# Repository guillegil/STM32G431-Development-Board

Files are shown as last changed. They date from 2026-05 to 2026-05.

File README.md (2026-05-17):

# STM32G431 Development Board

KiCad 10 design files for a small development board based on the STMicroelectronics
STM32G431CBT6 microcontroller (Cortex-M4F, 170 MHz, 128 KB flash, USB).

This is a personal learning project — my first custom-designed PCB, built as
preparation for a more complex nRF5340-based wireless keyboard development board.

## Features

- STM32G431CBT6 in LQFP-48 package (hand-solderable)
- USB-C connector for power and native USB device communication
- 3.3 V LDO regulator
- SWD programming header
- UART debug header
- User LED + user button
- Reset button + boot-mode jumper
- GPIO breakout headers for experimentation

## Project goals

- Learn KiCad 10 schematic and PCB design workflow
- Learn home reflow soldering (hot plate + hot air)
- Build a base for future Zephyr RTOS experimentation
- Prepare skills for a larger custom-keyboard project

## Status

🟡 In design — schematic in progress

## Tools used

- KiCad 10.x
- Zephyr RTOS / nRF Connect SDK (firmware, future)
- JLCPCB (PCB fabrication, planned)

## License

See [LICENSE](LICENSE). This project is open source under the MIT License.

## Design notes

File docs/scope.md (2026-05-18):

# STM32G431 Dev Board — Project Scope

**Project:** `stm32g431-devboard`
**Goal:** A learning-focused STM32 development board for KiCad practice and future firmware experimentation.
**Out of:** Commercial product, certification target, or anything that needs to "just work" without iteration.

---

## Goals (what success looks like)

1. Functional STM32G431 dev board that boots, runs firmware, and is debuggable
2. Hand-soldered by user (no PCBA service for v1)
3. Manufactured at JLCPCB, assembled in user's workshop
4. Used as both a learning artifact AND a "brain module" for future projects
5. Documents the user's KiCad and STM32 skills development

---

## In scope (locked feature list)

### Power
- USB-C input (GCT USB4085) with 5.1kΩ CC pull-downs
- Diode-OR power input: USB + external (JST-PH 2-pin) both Schottky-protected
- Dual LDO selector (AP2112K-3.3 + MCP1700-3302E/TT) via 3-pin jumper
- Power LEDs with disable jumpers (red on VBUS, green on +3V3_RAW)
- Current measurement jumper between +3V3_RAW and +3V3

### MCU support
- STM32G431CBT6 (LQFP-48)
- VDD decoupling: 3× 100nF + 1× 4.7µF
- VDDA filter: ferrite bead + 1µF + 10nF
- VREF+ selector jumper (internal +3V3A vs external via 1kΩ)
- VBAT tied to +3V3 (no battery backup)

### Programming & debug
- SWD 5-pin header
- Reset button + 100nF noise cap
- BOOT0 button (PB8) + 10kΩ pull-down
- USB-C handles DFU flashing + USB CDC virtual UART (firmware-level)
- Physical UART header (USART2 on PA2/PA3) as backup debug

### User I/O
- User LED on PA5 (1kΩ current limit)
- User button on PB1 with 10kΩ pull-up
- **3× WS2812B addressable RGB LEDs** on PA0 (TIM2_CH1)
- **74AHCT125 level shifter** (3.3V → 5V) for RGB data line

### Protection
- **USBLC6-2SC6 ESD protection** on USB D+/D− lines

### Connectivity
- **GPIO breakout: Black Pill style** (2× single-row 2.54mm headers, ~40-pin DIP form factor)
- Breadboard-friendly board width

### Documentation on PCB
- Pin labels / silkscreen legends
- Test points on key signals (VDD, GND, +3V3A, key debug points)
- Board name + version on silk
- Polarity markings on diodes, LEDs, electrolytic caps

---

## Explicitly OUT of scope (for v1)

These were considered and **deliberately deferred**:

- ❌ Battery management (TP4056 + DW01A + power path) — separate "Battery Management Board" project
- ❌ Buck/boost converter — LDO is sufficient for USB power; buck-boost adds complexity not needed here
- ❌ External crystal — STM32G4 has internal HSI48 + USB clock recovery, no crystal needed
- ❌ Wireless (BLE/WiFi) — separate nRF5340 project
- ❌ Mounting holes — not selected by user (can add to v2 if needed)
- ❌ Sensors (BME280, IMU, etc.) — out of scope
- ❌ Displays (OLED, LCD) — out of scope
- ❌ Audio codec — out of scope
- ❌ More than 3 RGB LEDs — sufficient for "addressable demo"
- ❌ APA102 (SPI-based RGB) — chose WS2812B for the DMA learning value

---

## v2 candidates (good ideas saved for later)

Captured here so we don't lose them, NOT committed to v1:

- Mounting holes (3.2mm clearance for M3 standoffs)
- USB-PD capable connector + IC (negotiate higher voltage from PD chargers)
- I²C-style "QWIIC" connector for sensor expansion
- Tag-Connect SWD pads (smaller footprint than 5-pin header)
- Battery charging via TP4056 + protection IC
- Crystal footprint (DNP by default) for future precise timing experiments
- 4-layer PCB upgrade for better RF/EMI
- Pin labels on bottom silk too (for when board is flipped)

---

## Status snapshot (update as we progress)

### ✅ Done in schematic
- USB-C power input + diode-OR
- Dual LDO selector + LEDs + jumpers
- Current measurement jumper
- MCU VDD/VSS/VBAT/VDDA decoupling
- VREF+ selector
- USB_DP/USB_DM correctly wired (PA12/PA11)
- SWD header
- Reset button + noise cap
- BOOT0 button + pull-down

### 🔜 Pending schematic (in priority order)
1. User LED (PA5) + 1kΩ resistor
2. User button (PB1) + 10kΩ pull-up
3. USBLC6-2SC6 ESD protection on USB data lines
4. Physical UART header (USART2 / PA2,PA3)
5. RGB LED block: 3× WS2812B + 74AHCT125 + decoupling
6. GPIO breakout headers (Black Pill style, both sides)

### ⏳ PCB layout phase (not started)
- Component placement
- Routing
- Ground pour
- Silkscreen labels & test points
- DRC + 3D check

### ⏳ Fabrication phase (not started)
- Gerbers
- BOM
- JLCPCB order

---

## When new feature ideas arise

**Rule:** if it's not in "In scope" above, default answer is **v2**.

The only exception: a genuine v1 requirement we missed. In that case, the trade-off should be:
- Add the new feature **and** remove something from v1, OR
- Add to v1 only if it's <30 min of work and doesn't change architecture

If the answer is "but it would be cool" → v2.

---

*Last updated: Session creating addressable RGB LED + GPIO breakout decisions*

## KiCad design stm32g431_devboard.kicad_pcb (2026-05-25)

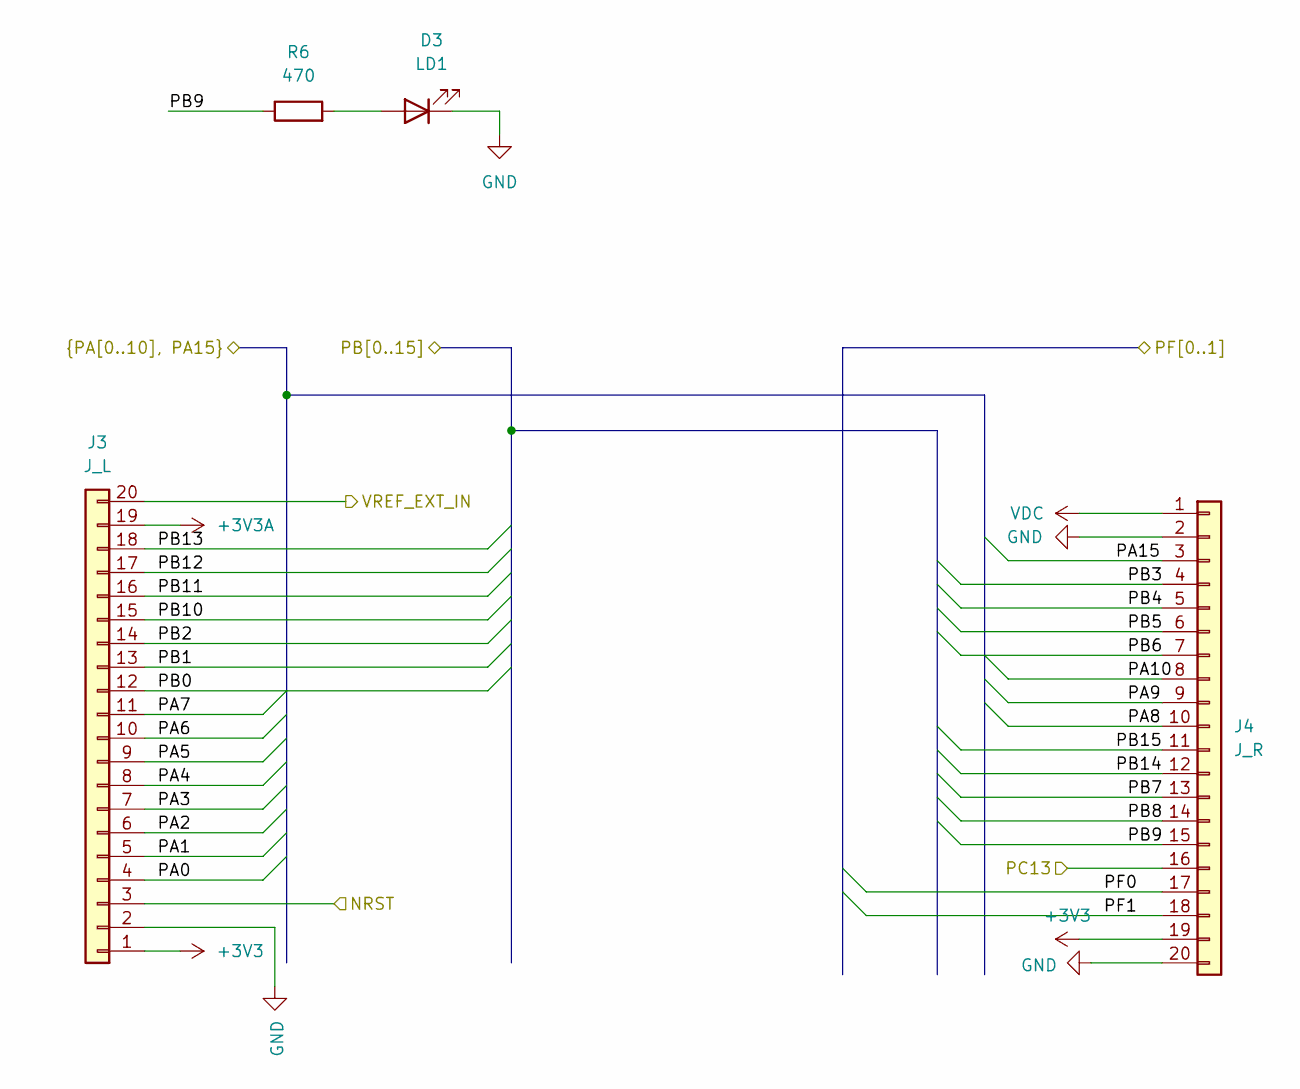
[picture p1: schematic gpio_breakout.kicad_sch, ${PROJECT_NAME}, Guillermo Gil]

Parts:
D3: LD1; LED_0603_1608Metric_Pad1.05x0.95mm_HandSolder
J3: J_L; PinHeader_1x20_P2.54mm_Vertical
J4: J_R; PinHeader_1x20_P2.54mm_Vertical
R6: 470; R_0603_1608Metric_Pad0.98x0.95mm_HandSolder

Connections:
+3V3: J3.1, J4.19; also elsewhere on the board
+3V3A: J3.19; also elsewhere on the board
/GPIO Breakout/PA0: J3.4; also elsewhere on the board
/GPIO Breakout/PA1: J3.5; also elsewhere on the board
/GPIO Breakout/PA2: J3.6; also elsewhere on the board
/GPIO Breakout/PA3: J3.7; also elsewhere on the board
/GPIO Breakout/PA4: J3.8; also elsewhere on the board
/GPIO Breakout/PA5: J3.9; also elsewhere on the board
/GPIO Breakout/PA6: J3.10; also elsewhere on the board
/GPIO Breakout/PA7: J3.11; also elsewhere on the board
/GPIO Breakout/PA8: J4.10; also elsewhere on the board
/GPIO Breakout/PA9: J4.9; also elsewhere on the board
/GPIO Breakout/PA10: J4.8; also elsewhere on the board
/GPIO Breakout/PA15: J4.3; also elsewhere on the board
/GPIO Breakout/PB0: J3.12; also elsewhere on the board
/GPIO Breakout/PB1: J3.13; also elsewhere on the board
/GPIO Breakout/PB2: J3.14; also elsewhere on the board
/GPIO Breakout/PB3: J4.4; also elsewhere on the board
/GPIO Breakout/PB4: J4.5; also elsewhere on the board
/GPIO Breakout/PB5: J4.6; also elsewhere on the board
/GPIO Breakout/PB6: J4.7; also elsewhere on the board
/GPIO Breakout/PB7: J4.13; also elsewhere on the board
/GPIO Breakout/PB8: J4.14; also elsewhere on the board
/GPIO Breakout/PB9: J4.15, R6.1; also elsewhere on the board
/GPIO Breakout/PB10: J3.15; also elsewhere on the board
/GPIO Breakout/PB11: J3.16; also elsewhere on the board
/GPIO Breakout/PB12: J3.17; also elsewhere on the board
/GPIO Breakout/PB13: J3.18; also elsewhere on the board
/GPIO Breakout/PB14: J4.12; also elsewhere on the board
/GPIO Breakout/PB15: J4.11; also elsewhere on the board
/GPIO Breakout/PF0: J4.17; also elsewhere on the board
/GPIO Breakout/PF1: J4.18; also elsewhere on the board
/GPIO Breakout/VREF_EXT_IN: J3.20; also elsewhere on the board
/MCU/NRST: J3.3; also elsewhere on the board
/MCU/PC13: J4.16; also elsewhere on the board
GND: D3.1 (K), J3.2, J4.2, J4.20; also elsewhere on the board
unnamed: D3.2 (A), R6.2
VDC: J4.1; also elsewhere on the board

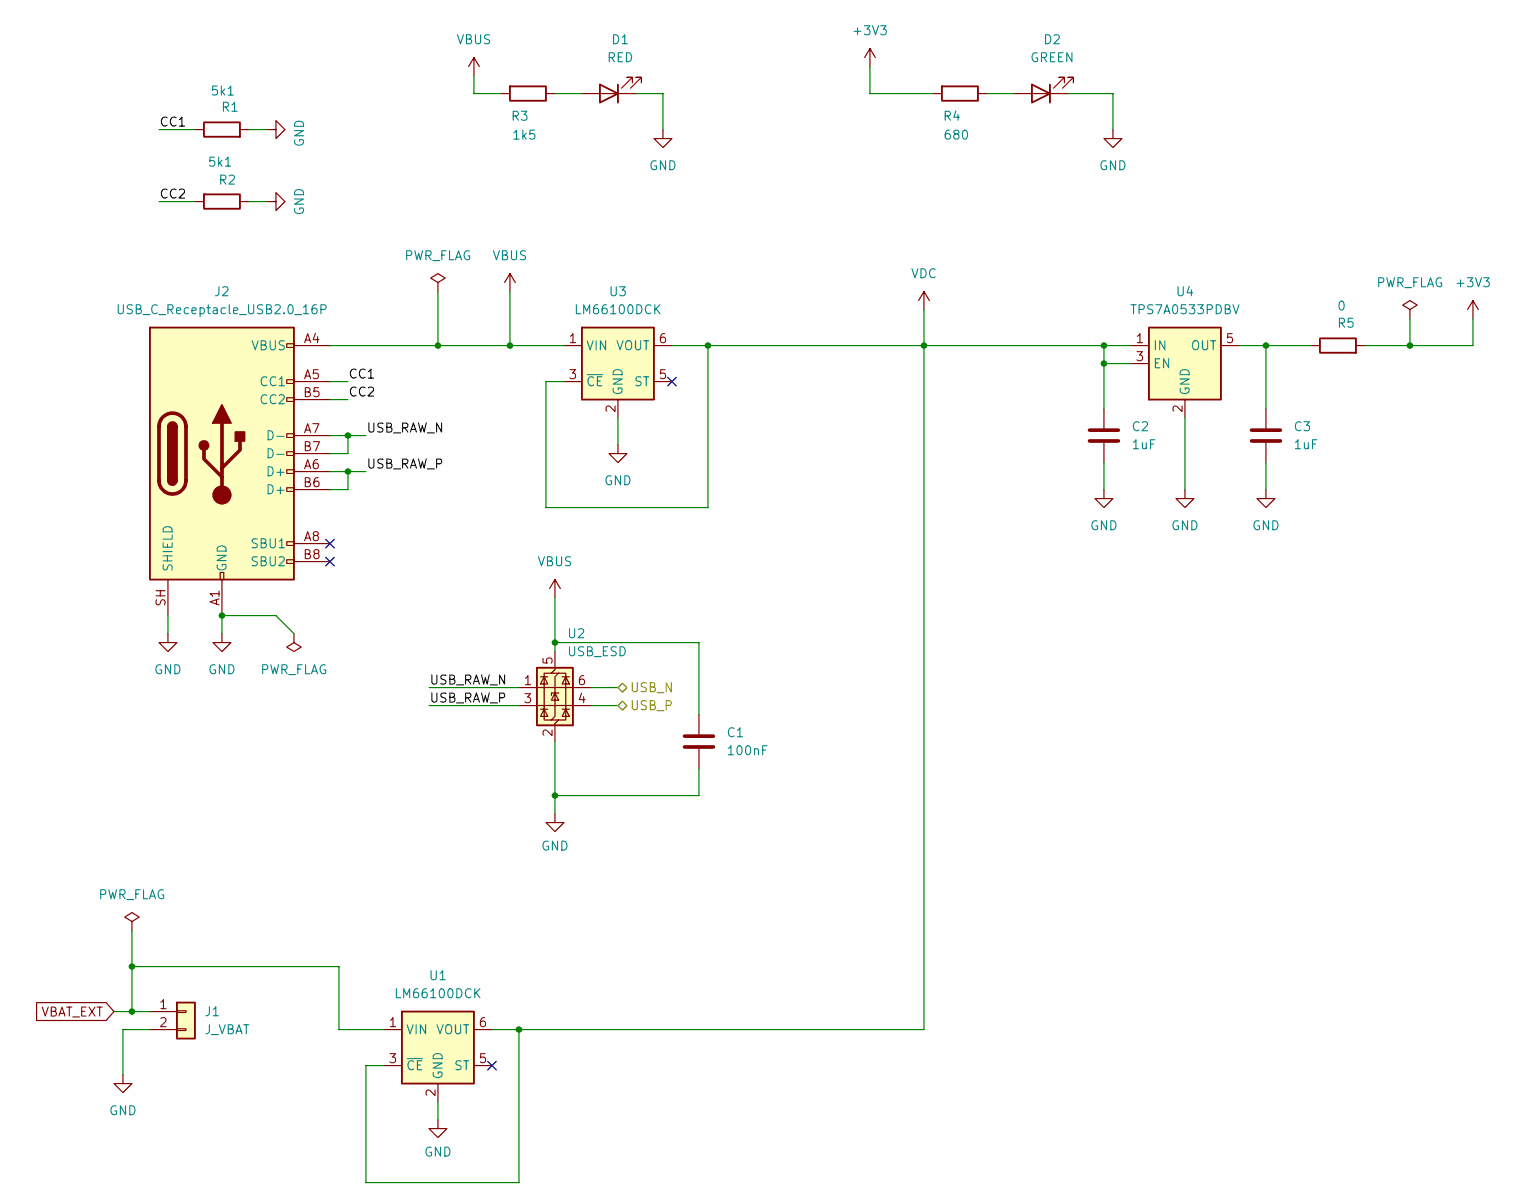
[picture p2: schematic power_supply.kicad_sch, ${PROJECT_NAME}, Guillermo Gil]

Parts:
C1: 100nF; C_0603_1608Metric_Pad1.08x0.95mm_HandSolder
C2, C3: 1uF; C_0603_1608Metric_Pad1.08x0.95mm_HandSolder
D1: RED; LED_0603_1608Metric_Pad1.05x0.95mm_HandSolder
D2: GREEN; LED_0603_1608Metric_Pad1.05x0.95mm_HandSolder
J1: J_VBAT; PinHeader_1x02_P2.54mm_Vertical
J2: USB_C_Receptacle_USB2.0_16P; USB_C_Receptacle_GCT_USB4085
R1, R2: 5k1; R_0603_1608Metric_Pad0.98x0.95mm_HandSolder
R3: 1k5; R_0603_1608Metric_Pad0.98x0.95mm_HandSolder
R4: 680; R_0603_1608Metric_Pad0.98x0.95mm_HandSolder
R5: 0; R_0603_1608Metric_Pad0.98x0.95mm_HandSolder
U1, U3: LM66100DCK; SOT-363_SC-70-6
U2: USB_ESD; SOT-23-6
U4: TPS7A0533PDBV; SOT-23-5_HandSoldering

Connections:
+3V3: R4.2, R5.2; also elsewhere on the board
/MCU/USB_N: U2.6 (I/O1); also elsewhere on the board
/MCU/USB_P: U2.4 (I/O2); also elsewhere on the board
/Power Supply/CC1: J2.A5 (CC1), R1.1
/Power Supply/CC2: J2.B5 (CC2), R2.2
/Power Supply/USB_RAW_N: J2.A7 (D-), J2.B7 (D-), U2.1 (I/O1)
/Power Supply/USB_RAW_P: J2.A6 (D+), J2.B6 (D+), U2.3 (I/O2)
GND: C1.2, C2.2, C3.2, D1.1 (K), D2.1 (K), J1.2, J2.A1 (GND), J2.A12 (GND), J2.B1 (GND), J2.B12 (GND), J2.SH (SHIELD), R1.2, R2.1, U1.2 (GND), U2.2 (GND), U3.2 (GND), U4.2 (GND); also elsewhere on the board
unnamed: D1.2 (A), R3.1
unnamed: D2.2 (A), R4.1
unnamed: C3.1, R5.1, U4.5 (OUT)
VBAT_EXT: J1.1, U1.1 (VIN)
VBUS: C1.1, J2.A4 (VBUS), J2.A9 (VBUS), J2.B4 (VBUS), J2.B9 (VBUS), R3.2, U2.5 (VBUS), U3.1 (VIN)
VDC: C2.1, U1.3 (~CE), U1.6 (VOUT), U3.3 (~CE), U3.6 (VOUT), U4.1 (IN), U4.3 (EN); also elsewhere on the board

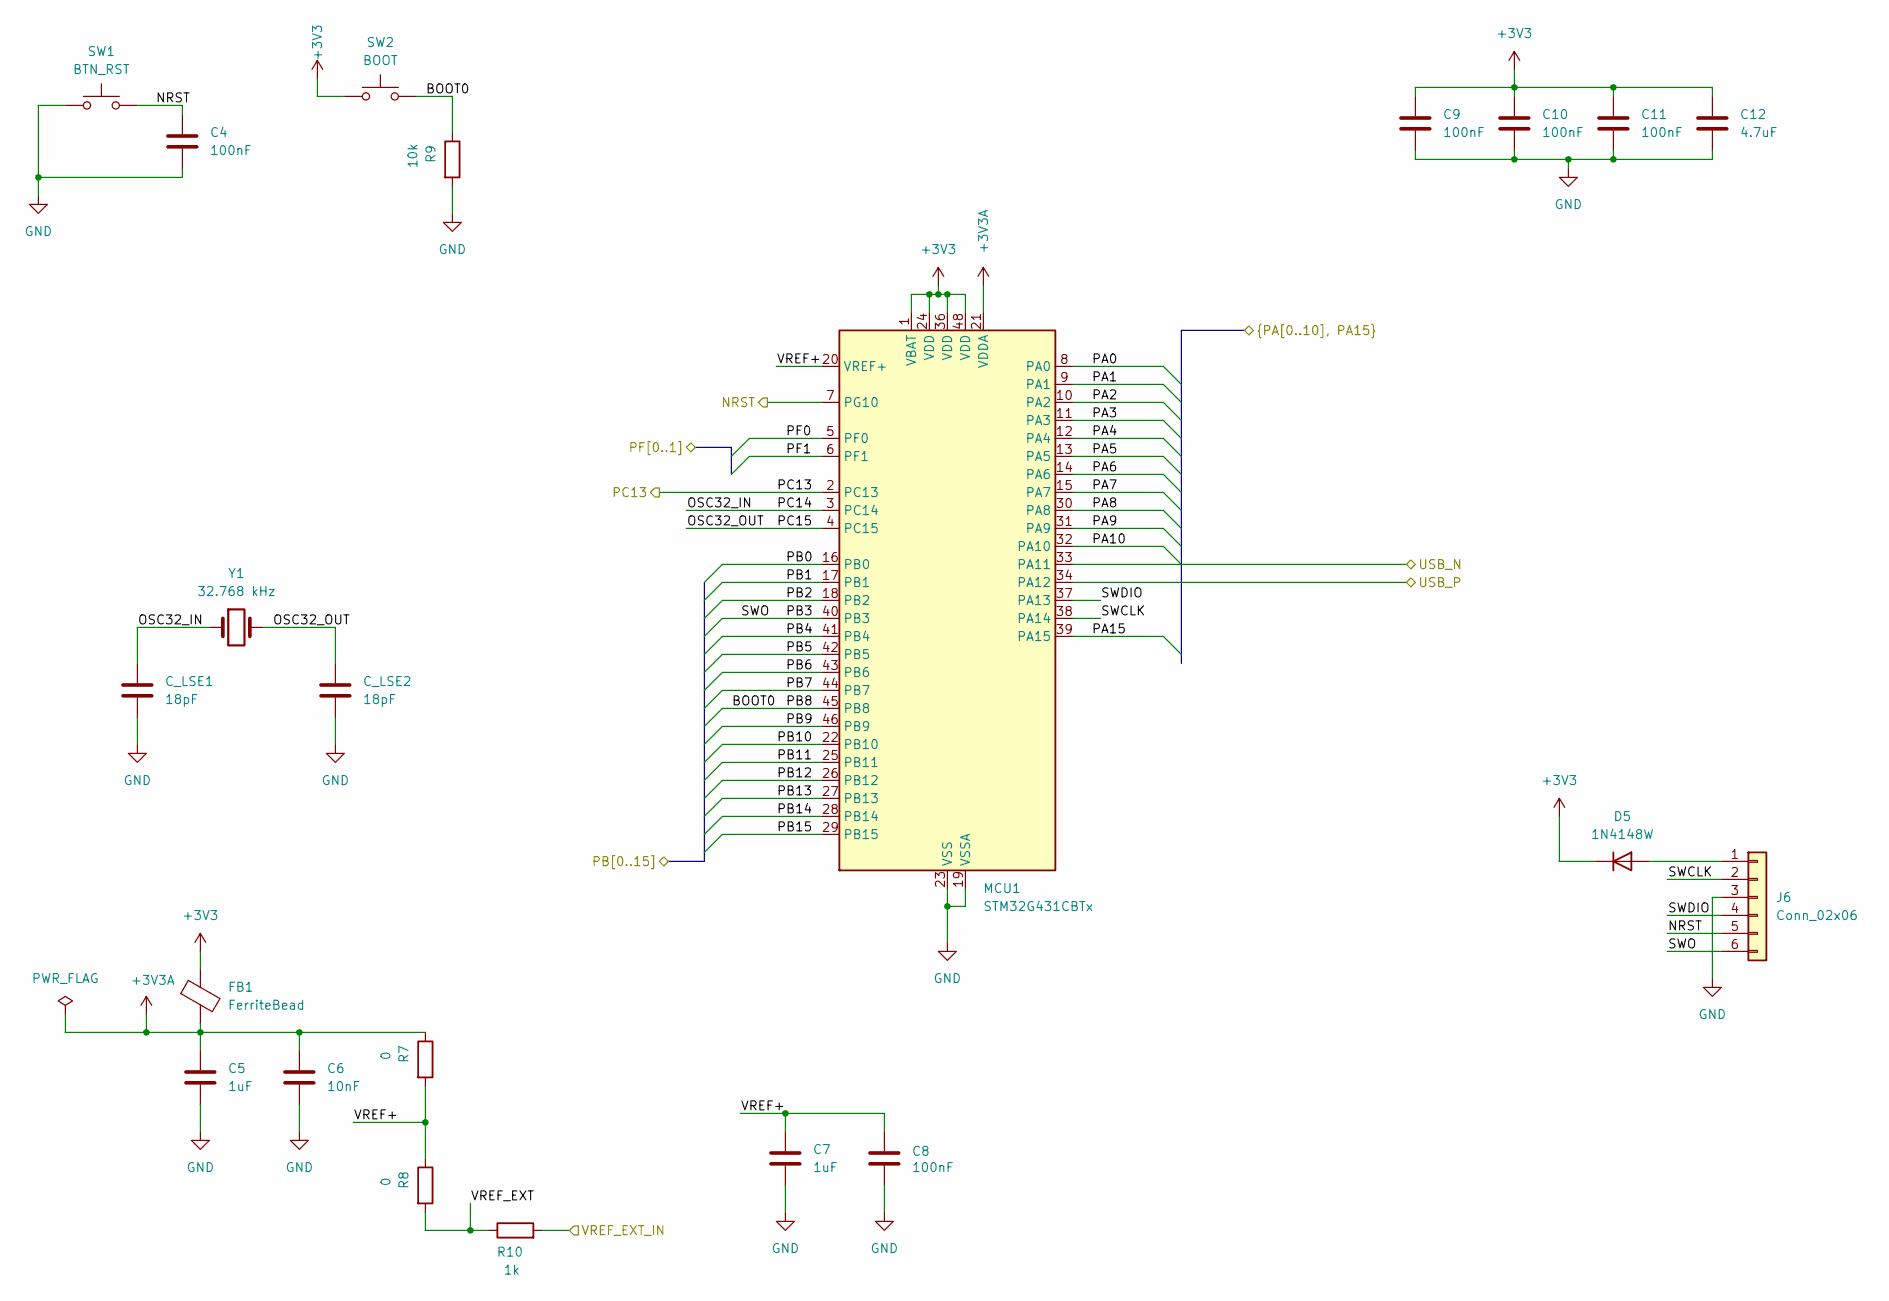
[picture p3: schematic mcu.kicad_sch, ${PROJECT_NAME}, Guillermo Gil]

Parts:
C4, C8, C9, C10, C11: 100nF; C_0603_1608Metric_Pad1.08x0.95mm_HandSolder
C5, C7: 1uF; C_0603_1608Metric_Pad1.08x0.95mm_HandSolder
C6: 10nF; C_0603_1608Metric_Pad1.08x0.95mm_HandSolder
C12: 4.7uF; C_0603_1608Metric_Pad1.08x0.95mm_HandSolder
C_LSE1, C_LSE2: 18pF; C_0603_1608Metric_Pad1.08x0.95mm_HandSolder
D5: 1N4148W; D_SOD-323
FB1: FerriteBead; L_0603_1608Metric_Pad1.05x0.95mm_HandSolder
J6: Conn_02x06; PinHeader_2x03_P2.54mm_Vertical_SMD
MCU1: STM32G431CBTx; LQFP-48_7x7mm_P0.5mm
R7, R8: 0; R_0603_1608Metric_Pad0.98x0.95mm_HandSolder
R9: 10k; R_0603_1608Metric_Pad0.98x0.95mm_HandSolder
R10: 1k; R_0603_1608Metric_Pad0.98x0.95mm_HandSolder
SW1: BTN_RST; SW_SPST_PTS810
SW2: BOOT; SW_SPST_PTS810
Y1: 32.768 kHz; Crystal_SMD_3215-2Pin_3.2x1.5mm

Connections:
+3V3: C9.1, C10.1, C11.1, C12.1, D5.1 (K), FB1.1, MCU1.1 (VBAT), MCU1.24 (VDD), MCU1.36 (VDD), MCU1.48 (VDD), SW2.1; also elsewhere on the board
+3V3A: C5.1, C6.1, FB1.2, MCU1.21 (VDDA), R7.1; also elsewhere on the board
/GPIO Breakout/PA0: MCU1.8 (PA0); also elsewhere on the board
/GPIO Breakout/PA1: MCU1.9 (PA1); also elsewhere on the board
/GPIO Breakout/PA2: MCU1.10 (PA2); also elsewhere on the board
/GPIO Breakout/PA3: MCU1.11 (PA3); also elsewhere on the board
/GPIO Breakout/PA4: MCU1.12 (PA4); also elsewhere on the board
/GPIO Breakout/PA5: MCU1.13 (PA5); also elsewhere on the board
/GPIO Breakout/PA6: MCU1.14 (PA6); also elsewhere on the board
/GPIO Breakout/PA7: MCU1.15 (PA7); also elsewhere on the board
/GPIO Breakout/PA8: MCU1.30 (PA8); also elsewhere on the board
/GPIO Breakout/PA9: MCU1.31 (PA9); also elsewhere on the board
/GPIO Breakout/PA10: MCU1.32 (PA10); also elsewhere on the board
/GPIO Breakout/PA15: MCU1.39 (PA15); also elsewhere on the board
/GPIO Breakout/PB0: MCU1.16 (PB0); also elsewhere on the board
/GPIO Breakout/PB1: MCU1.17 (PB1); also elsewhere on the board
/GPIO Breakout/PB2: MCU1.18 (PB2); also elsewhere on the board
/GPIO Breakout/PB3: J6.6, MCU1.40 (PB3); also elsewhere on the board
/GPIO Breakout/PB4: MCU1.41 (PB4); also elsewhere on the board
/GPIO Breakout/PB5: MCU1.42 (PB5); also elsewhere on the board
/GPIO Breakout/PB6: MCU1.43 (PB6); also elsewhere on the board
/GPIO Breakout/PB7: MCU1.44 (PB7); also elsewhere on the board
/GPIO Breakout/PB8: MCU1.45 (PB8), R9.1, SW2.2; also elsewhere on the board
/GPIO Breakout/PB9: MCU1.46 (PB9); also elsewhere on the board
/GPIO Breakout/PB10: MCU1.22 (PB10); also elsewhere on the board
/GPIO Breakout/PB11: MCU1.25 (PB11); also elsewhere on the board
/GPIO Breakout/PB12: MCU1.26 (PB12); also elsewhere on the board
/GPIO Breakout/PB13: MCU1.27 (PB13); also elsewhere on the board
/GPIO Breakout/PB14: MCU1.28 (PB14); also elsewhere on the board
/GPIO Breakout/PB15: MCU1.29 (PB15); also elsewhere on the board
/GPIO Breakout/PF0: MCU1.5 (PF0); also elsewhere on the board
/GPIO Breakout/PF1: MCU1.6 (PF1); also elsewhere on the board
/GPIO Breakout/VREF_EXT_IN: R10.2; also elsewhere on the board
/MCU/NRST: C4.1, J6.5, MCU1.7 (PG10), SW1.2; also elsewhere on the board
/MCU/OSC32_IN: C_LSE1.1, MCU1.3 (PC14), Y1.1
/MCU/OSC32_OUT: C_LSE2.1, MCU1.4 (PC15), Y1.2
/MCU/PC13: MCU1.2 (PC13); also elsewhere on the board
/MCU/SWCLK: J6.2, MCU1.38 (PA14)
/MCU/SWDIO: J6.4, MCU1.37 (PA13)
/MCU/USB_N: MCU1.33 (PA11); also elsewhere on the board
/MCU/USB_P: MCU1.34 (PA12); also elsewhere on the board
/MCU/VREF+: C7.1, C8.1, MCU1.20 (VREF+), R7.2, R8.1
/MCU/VREF_EXT: R8.2, R10.1
GND: C4.2, C5.2, C6.2, C7.2, C8.2, C9.2, C10.2, C11.2, C12.2, C_LSE1.2, C_LSE2.2, J6.3, MCU1.19 (VSSA), MCU1.23 (VSS), MCU1.35 (VSS), MCU1.47 (VSS), R9.2, SW1.1; also elsewhere on the board
unnamed: D5.2 (A), J6.1

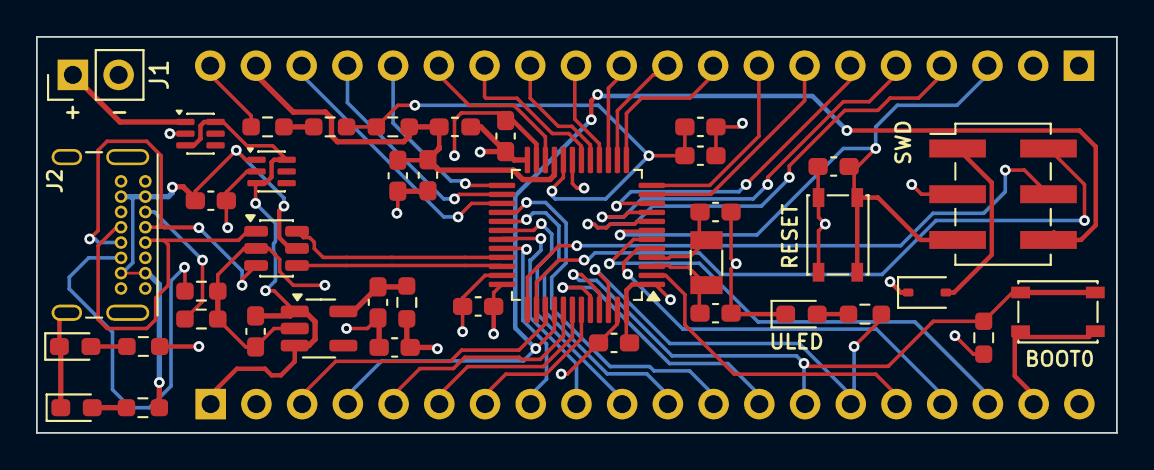
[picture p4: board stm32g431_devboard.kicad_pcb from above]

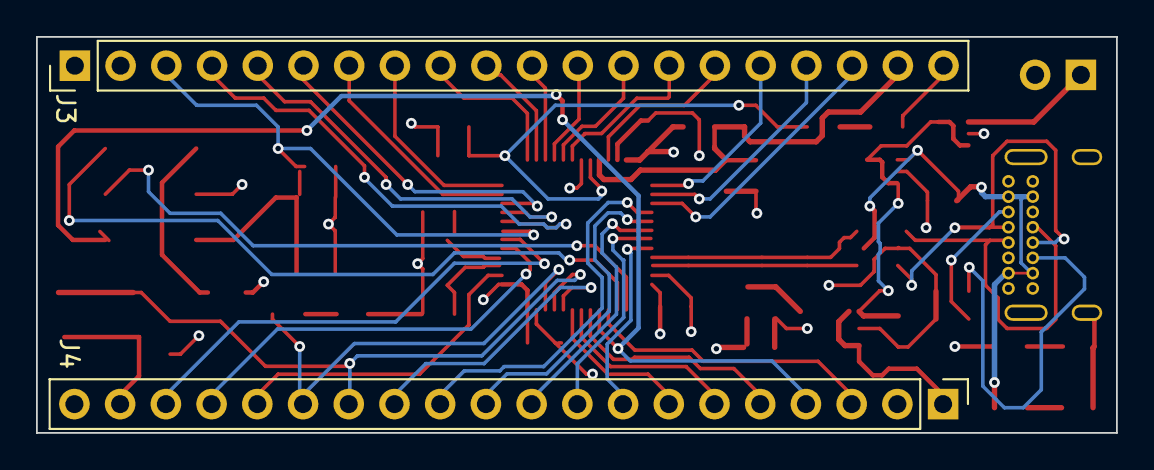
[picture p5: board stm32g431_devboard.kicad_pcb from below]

Board: 4 copper layers, 60.0 x 22.0 mm, 42 parts (2 on the bottom side), 56 nets.

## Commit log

2026-05-17 Place STM32G431CBTx MCU symbol
    [stm32g431_devboard.kicad_pcb, stm32g431_devboard.kicad_sch]
2026-05-17 Add: Power Supply hierarchical sheet
    [power_supply.kicad_sch, stm32g431_devboard.kicad_sch]
2026-05-18 Add dual-LDO selector, power LEDs, current measurement jumper
    [power_supply.kicad_sch]
2026-05-18 Complete MCU power, debug, and boot circuits; add scope doc
    Schematic additions:
    - Add second Schottky on USB VBUS for full diode-OR protection
    - Wire VBAT, VSS, VSSA to power nets
    - Add VDD decoupling: 3x 100nF + 1x 4.7uF bulk
    - Add VDDA filter: ferrite bead + 1uF + 10nF
    - Add VREF+ selector jumper with decoupling and external input
    - Wire USB_DP/USB_DM to PA12/PA11 (corrected pinout)
    - Add SWD 5-pin header on PA13/PA14/NRST
    - Add reset button with 100nF noise cap
    - Add BOOT0 button on PB8 with 10k pull-down
    Project documentation:
    - Add docs/scope.md locking v1 feature list and v2 candidates
    [power_supply.kicad_sch, stm32g431_devboard.kicad_sch]
2026-05-19 feat(schematic): complete v0.1 schematic for STM32G431 dev board
    Three-sheet hierarchical design with clean ERC pass (0 errors, 0 warnings).
    MCU (mcu.kicad_sch):
    - STM32G431CBTx LQFP-48
    - VDD decoupling (3× 100nF + 1× 4.7µF)
    - VDDA filter via ferrite bead + 1µF + 10nF
    - VREF+ selector jumper (internal +3V3A or external via 1kΩ series)
    - SWD 5-pin header
    - Reset button + 100nF noise cap
    - BOOT0 button + 10kΩ pull-down
    Power Supply (power_supply.kicad_sch):
    - USB-C input (GCT USB4085) with 5.1kΩ CC pull-downs
    - Diode-OR (SS14): USB + external JST 2-pin
    - Dual LDO selector: AP2112K-3.3 and MCP1700-3302
    - Current measurement jumper
    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
    [gpio_breakout.kicad_sch, mcu.kicad_sch, power_supply.kicad_sch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]
2026-05-19 Created PCB editor, configure for JLCPCB standards
    Additionally, created a specific library for castellard jumpers
    [gpio_breakout.kicad_sch, power_supply.kicad_sch, stm32g431_devboard.kicad_pcb]
2026-05-20 Started PCB placing
    [gpio_breakout.kicad_sch, mcu.kicad_sch, power_supply.kicad_sch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]
2026-05-20 v0.2: low-power redesign — single LDO, ideal diodes, LSE, castellated SWD
    Power supply:
    - Replace dual LDO (AP2112K + MCP1700) with single TPS7A0233PDBV
    (25 nA Iq nanopower; EN tied to IN per datasheet)
    - Replace SS14 Schottky diodes with LM66100 ideal diode controllers
    in diode-OR configuration (CE tied to VOUT for RCB mode)
    - Remove jumpers J2 (LDO_SEL), J3 (LED_VBUS), J4 (LED_3V3)
    - Replace JST battery connector with castellated header J_VBAT
    - Replace J5 IMEAS jumper with 0R bridge
    - Rename diode-OR output net to VDC
    MCU:
    - Add LSE crystal Y1 (32.768 kHz ABS07) with 18 pF load caps
    - Dedicate PC14/PC15 to LSE oscillator (removed from J_R breakout)
    - Wire BOOT0 net to PB8 (requires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
    [gpio_breakout.kicad_sch, mcu.kicad_sch, power_supply.kicad_sch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]
2026-05-25 Finish routing
    [gpio_breakout.kicad_sch, mcu.kicad_sch, power_supply.kicad_sch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]
